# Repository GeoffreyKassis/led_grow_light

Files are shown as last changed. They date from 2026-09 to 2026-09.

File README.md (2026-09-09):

# Grow-light

USB-C PD grow light in two assemblies: an FR-4 controller (`MAIN_BOARD/`) and
a one-layer aluminum LED panel (`LED_BOARD/`), joined by an 8-wire 2×4 IDC
harness. Schematic connectivity and the as-drawn BOM come from KiCad
(`MAIN_BOARD/production/`, `LED_BOARD/production/`). This file records *why*
parts and numbers are what they are.

## Architecture

USB-C is the only power inlet. An **HUSB238** PD sink negotiates the contract
over I2C. An **STM8S003F3** requests **9 V or 12 V** (never 20 V) and PWM-dims
four **TPS61165** boost channels from `PC6`. Each channel drives one isolated
LED string: four 4000 K whites plus one 660 nm red in series.

Boost, not buck: string forward voltage is ~15.8 V, so the converter must sit
above that. TPS61165 VIN is 3–18 V recommended (20 V abs max). A 20 V PDO
leaves no boost headroom and violates that VIN rating.

On/off and dimming are MCU functions. There is no panel switch or pot.

## LED current and power

TPS61165 FB is **200 mV**. String current is set only by the sense resistor:

```
I_LED = V_FB / R_sense
      = 0.200 V / 0.82 Ω
      ≈ 0.244 A
```

A 1 Ω 1206 Basic (`C17928`) is a same-footprint swap: **0.200 A**. Dissipation
in the sense resistor is `I²R` ≈ 49 mW at 0.244 A, so 1206 is thermal margin,
not a requirement.

Nominal string voltage and power (generic 3 V whites / ~3 V red):

```
V_string ≈ 4 × 3.2 V + 3.0 V = 15.8 V
P_string ≈ 15.8 V × 0.244 A  ≈ 3.85 W
P_LEDs   ≈ 4 × 3.85 W        ≈ 15.4 W
```

XP-E2 / Oslon reds are ~2.0–2.1 V, which drops `V_string` a volt or so; the
boost still works. Input current is about **1.7 A at 9 V** or **1.3 A at 12 V**
plus converter and LDO overhead. Product class is still ~20 W at the USB-C
port.

Open-string OVP on TPS61165 is ~38 V. Do not hot-plug the LED harness with
drivers enabled.

## Controller choices

| Role | Part | Why |
|---|---|---|
| PD sink | HUSB238 `C7471904` (DFN-10 3×3) | I2C so firmware picks 9/12 V. CH224K is also Extended and has no I2C. |
| MCU | STM8S003F3P6TR `C52717` | Preferred (no $3 feeder). I2C + TIM1 PWM on remapped `PC6` (set OPT2 AFR0). |
| LED drivers | TPS61165**DRVR** `C122568` ×4 | WSON-6-EP 2×2. Do not pick the SOT-23 `C58756`. VIN 3–18 V, Vout to 38 V. |
| Inductors | CENKER CKCS4030 22 µH `C354592` | 1.0 A Irms / 1.3 A sat. Peak ~0.5 A at 9 V VIN, ~0.83 A at 5 V. No Basic 1 A 4×4. |
| Sense | 820 mΩ 1206 `C2907361` | Sets 0.244 A. True Extended; only same-footprint Basic swap is 1 Ω `C17928`. |
| Freewheel | B5819WS SOD-323 `C7420331` | 40 V / 1 A. Preferred, not a $3 line. |
| Load switch | AO3401A + BZX84C10 + 10 Ω | HUSB238 GATE after contract. 10 V VGS clamp; AO3401A is ±12 V. |
| 3.3 V | HT7533-1 | From switched VIN, 100 mA. Fine at 9/12 V; watch dissipation `(VIN−3.3)×I`. |
| USB-C | 16P `C2927039` | Cheap Extended 7.35 mm. Listing is 3 A / **5 V**; 9–12 V PD is common use but the listing is the weak one. `C165948` is 20 V / 5 A, still Extended. |
| CC ESD | USBLC6-2SC6 `C7519` | CC1/CC2 only. True Extended; no Basic SOT-23-6 equivalent. Do not tie pin 5 to 12 V. |
| Input protect | F1 3 A / 24 V PTC `C7500481`; D9 SMAJ15A | PTC is true Extended. SMAJ15A high-current clamp is ~24.4 V vs TPS61165 20 V abs max — a known gap, not a precise 15 V wall. |

HUSB238 **R2** 49.9 kΩ / **R3** 5.1 kΩ are the typical-app VSET/ISET pair.
5.1 kΩ ISET is about 1.5 A. 49.9 kΩ is **not** a datasheet VSET tap; firmware
must request 9/12 V so the default contract cannot land on 20 V.

TPS61165 VIN ceramics are 25 V. That is correct for 9/12 V and is not a 20 V
design.

## JLCPCB assembly (controller)

Economic PCBA charges **$3 per unique true Extended line**. Preferred parts
often show as “Extended” in the cart and **do not** get that fee.

**No $3 (Preferred):** D1–D4 B5819WS, D8 BZX84C10, D9 SMAJ15A, R2 49.9 kΩ, U2 STM8.

**$3 each (true Extended):** U1 HUSB238, TPS61165DRVR (one fee for four),
L1–L4 (one fee), J2 USB-C, F1 PTC, U3 USBLC6, R4–R7 820 mΩ.

Leave **J1, J3, J4** unselected and solder the TH headers yourself (avoids
the hand-solder surcharge). The only cart swap that drops a $3 line without
touching copper is **R4–R7 → `C17928` 1 Ω**.

## LED panel

Intent is a **1-layer aluminum** MCPCB: SMT on the copper face, no vias, no
through-hole parts (leads can short to the aluminum). The saved KiCad board
is already electrically single-layer (all F.Cu, no B.Cu copper, no vias) but
still declares two copper layers. Set copper layers to **1** before Gerbers
and order aluminum / 1 layer (typically 1.6 mm, 1 oz, white mask).

The checked-in `LED_BOARD/production/grow-light-LEDS.zip` is deliberately
plotted as a **front-copper-only** fabrication package. Do not regenerate it
with KiCad's automatic layer selection while the source board still declares
two copper layers, or an empty `B_Cu` file will be added and the upload may be
treated as a two-layer board.

Do **not** JLC-assemble this panel. Fab bare aluminum; populate by hand
(preheat / hot plate — the core sinks iron heat).

### Heatsink and camera mount

Selected heatsink: **Advanced Thermal Solutions
`ATS-CPX070070025-136-C1-R0`**. It is a 70 × 70 × 25 mm blue-anodized,
coarse-pitch X-cut aluminum heatsink. ATS specifies **2.17 °C/W at 100 LFM**
(~0.5 m/s) airflow; it does not publish a natural-convection value. The LED
panel is expected to put about **10–12 W of heat** into the MCPCB (15.4 W
electrical LED input less emitted light). Thus this heatsink is suitable with
intentional airflow, but is not a qualified passive full-brightness solution.
For a passive revision, target a heatsink rated **≤2.0 °C/W natural
convection** (≤1.5 °C/W preferred for a warm grow enclosure).

The ATS part has a four-corner **63.0 × 63.0 mm** mounting pattern. Direct
MCPCB mounting uses four **3.2 mm NPTH** clearance holes on that grid (centres
3.5 mm from the edges of a 70 mm square), M3 screws, and a thin layer of
thermal grease/TIM against the flat heatsink base. These are mechanical holes,
not component leads: keep front copper clear and insulate the LED-side screw
heads from copper/exposed core with shoulder washers. The current board has no
mounting holes; add them through the KiCad workflow before relying on this
mounting method.

The **1/4-20 UNC camera interface** belongs on a separate metal crossbar or
saddle bolted to the ATS factory holes, not in the heatsink or MCPCB. Capture
a steel 1/4-20 coupling nut in that crossbar for adequate thread engagement;
include an anti-rotation feature and a separate safety tether for overhead use.

This layout: **16× 3030 2-pad** whites (asymmetric A/K) and **4× 3535-3P**
reds (A/K + isolated thermal; pad 3 is unnetted). A 3030 *outline* is not a
3030 *footprint*.

### Whites

Drive ~0.244 A needs a **3 V, ~350–400 mA** 3030. Not mid-power 65 mA parts.

| MPN | Use |
|---|---|
| Cree `JK3030AWT-P-U40EA0000-N0000001` (`C17398997`) | 90 CRI, ~126 lm @ 350 mA. On the LCSC leftover list. |
| Cree `JK3030AWT-P-H40EA0000-N0000001` | Same 3 V / 400 mA max, **80 CRI**, ~154 lm @ 350 mA (~22% more light). Better for plants. |
| Everlight `XI3030P/KKE-5M4014034Z35/2N` | Still manufactured. 4000 K, 80 CRI, 3.05 V, 145 lm @ 350 mA, **max 350 mA**. 3.24×3.00 mm; check pads. |

**Cree JK3030 3 V P class is EOL** (PCN-06128, last-time buy 2026-09-04).
Remaining Digi-Key/Mouser reels are leftover. Cree’s named substitute is
`JB3030SWT-J-H40EA0000-NZ000001` (JB3030S 3 V J class): 65 mA test / 480 mA
max, **757 / Samsung-style pads**, not a 1:1 clone of JK3030 P.

Do not buy 6 V Cree `…EB…` 3030s (Vf ~6.1 V; four of those plus a red blow
the string budget and the 244 mA drive). Do not use Samsung LM301H / EVO
(EOL, and typically max ~200 mA).

### Reds

| MPN | Use |
|---|---|
| Silverlight `M3535N1IRG6U12-660NM` (`C2833507`) | Generic 3535 on LCSC. Weak horticulture part. |
| Cree XP-E2 Photo Red `XPEBPR-L1-0000-00D01` | **Still active.** 660 nm, 3.45 mm, ~2.05 V, 350 mA test / 1 A max. Closest 3535-class upgrade; confirm A/K vs the open thermal pad. |
| ams OSRAM `GH CSSRM6.24-VAA3-1-1-700-R33` | Best 660 nm (~4 µmol/J class). **3.0×3.0 mm ceramic + ~2.2 mm dome, 3-pad (A/K/thermal).** Will not solder to the 2-pad white 3030 or the 3535-3P. |

Samsung LH351H 660 nm is EOL (same lighting-LED shutdown: last ship 2025-12-31).

### Next revision — one footprint

To actually share lands, put the whole panel on **Oslon Square** (ceramic
3-pad 3.0 mm): red `GH CSSRM6.24` + white `GW CSSRM4.HW`. Same stencil,
same pad. Those whites are ~700 mA class and ~$1.50; at 0.244 A they run
cool but you pay 1 W prices. Do not mix Oslon Square pads with
Cree/Everlight 2-pad 3030 whites.

## Firmware notes

- Remap STM8 **OPT2 AFR0** so TIM1_CH1 appears on `PC6`. Default pinout does
  not.
- Hold CTRL low through reset and PD negotiation. Read the contract before
  enabling PWM.
- ~20 kHz PWM is a reasonable starting point; confirm startup does not enter
  TPS61165 EasyScale.
- Four channels at once, on the intended heatsink, after thermal equilibrium.

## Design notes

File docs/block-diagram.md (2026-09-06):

# 20 W USB-C PD Grow Light — System Plan

As-built from the KiCad schematics (main board `grow-light.kicad_sch` +
`led_driver.kicad_sch`, LED panel `grow-light-LEDS.kicad_sch`). Two
assemblies: an FR-4 controller board and a one-layer aluminum LED panel,
joined by an 8-wire LED harness on 2×4 IDC headers. USB-C input is the
power source. An STM8 MCU requests the PD contract over I2C and PWM-dims
four independent TPS61165 boost LED drivers.

## Block diagram

```mermaid
flowchart TB
  PSU["USB-C PD charger"]

  subgraph FR4["FR-4 controller board"]
    J2["J2 USB-C 16P"]
    U3["U3 USBLC6-2SC6<br/>CC1 / CC2 ESD"]
    F1["F1 3 A / 24 V PTC"]
    D7["D7 SMAJ24A TVS"]
    U1["U1 HUSB238<br/>PD sink · I2C"]
    Q1["Q1 AO3401A PMOS<br/>D8 10 V VGS clamp"]
    U7["U7 HT7533 3.3 V LDO"]
    U2["U2 STM8S003F3<br/>I2C to U1 · PWM dim"]
    S1["S1 button"]
    S2["S2 button"]
    Dstat["D5 red / D6 green"]
    J3["J3 PROG"]
    J4["J4 UART"]
    DRV1["U4 TPS61165 · string 1"]
    DRV2["U5 TPS61165 · string 2"]
    DRV3["U11 TPS61165 · string 3"]
    DRV4["U12 TPS61165 · string 4"]
    J1["J1 2×4 IDC"]
  end

  subgraph LED["Aluminum LED panel + heatsink"]
    JP["J1 2×4 IDC SMD"]
    S1s["String 1: 4× 4000 K + 660 nm"]
    S2s["String 2: 4× 4000 K + 660 nm"]
    S3s["String 3: 4× 4000 K + 660 nm"]
    S4s["String 4: 4× 4000 K + 660 nm"]
  end

  PSU -->|"VBUS"| J2
  PSU -->|"CC1 / CC2"| J2
  J2 --> U3 --> U1
  J2 --> F1 --> U1
  F1 --> D7
  F1 --> Q1
  U1 -->|"GATE"| Q1
  Q1 -->|"switched VIN"| DRV1
  Q1 --> DRV2
  Q1 --> DRV3
  Q1 --> DRV4
  Q1 --> U7 --> U2
  U2 -->|"I2C SDA/SCL"| U1
  U2 -->|"PC6 PWM"| DRV1
  U2 --> DRV2
  U2 --> DRV3
  U2 --> DRV4
  S1 --> U2
  S2 --> U2
  U2 --> Dstat
  U2 --- J3
  U2 --- J4
  DRV1 --> J1
  DRV2 --> J1
  DRV3 --> J1
  DRV4 --> J1
  J1 -->|"H1 harness"| JP
  JP --> S1s
  JP --> S2s
  JP --> S3s
  JP --> S4s
```

## Power path

1. USB-C **J2** VBUS through **F1** (3 A hold / 24 V PTC, C7500481) and
   **D7** (SMAJ24A). **U3** protects CC1/CC2 only.
2. **U1** (HUSB238) drives **Q1** (AO3401A) after a PD contract. **D8**
   (BZX84C10) clamps Q1 VGS. **R1** (10 Ω) is the GATE series resistor.
3. Switched VIN feeds four **TPS61165DRV** boost LED drivers and **U7**
   (HT7533, 3.3 V / 100 mA) for the MCU.
4. TPS61165 VIN is 3–18 V. Firmware on **U2** must request a PDO of
   **9 V or 12 V** (not 20 V). A 15.8 V LED string needs boost headroom
   below that voltage.

## Control path

- **U2** STM8S003F3 (TSSOP-20) talks to U1 over I2C (`SDA` / `SCL`) and
  PWM-dims all four driver CTRL pins from `PC6`.
- **S1** (`PD3`) and **S2** (`PD4`) are on-board tactile buttons.
  **D5** (red) and **D6** (green) are 0805 status LEDs.
- **J3** is SWIM/NRST programming. **J4** is UART (`PD5` TX / `PD6` RX).
- There is no panel-mount power switch or dimmer pot. On/off and dimming
  are MCU functions.

## LED drive (per string)

Each hierarchical `led_driver` sheet is one boost channel:

| Item | Schematic |
|---|---|
| Driver | TPS61165DRV, WSON-6-EP, 1.2 MHz, 200 mV FB |
| Inductor | L1–L4 22 µH CENKER CKCS4030, LCSC **C354592**, 4×4×3.0 mm, 1.0 A / 1.3 A sat |
| Freewheel | D1–D4 B5819WS Schottky 40 V / 1 A, SOD-323, **C7420331** |
| Current sense | R4–R7 820 mΩ 1206, **C2907361** → ILED ≈ 200 mV / 0.82 Ω ≈ **0.244 A** |
| VIN cap | C2–C5 4.7 µF 25 V X5R 0805, **C1779** |
| Output cap | C8–C11 1 µF 50 V X5R 0603, **C15849** |
| COMP | C19–C22 220 nF 25 V X7R 0603, **C21120** |

Driver references on the root sheet: **U4, U5, U11, U12**.

## LED panel

Four electrically independent strings. Each string is four 4000 K whites
plus one 660 nm red in series (~15.8 V at 0.244 A ≈ 3.85 W).

| LEDs | Designators | Footprint |
|---|---|---|
| 16 × 4000 K white | D1–D4, D6, D7, D9–D12, D14–D17, D19, D20 | 3030 |
| 4 × 660 nm red | D5, D8, D13, D18 | 3535-3P |
| J1 | 2×4 IDC SMD | to main-board J1 |

The LED schematic does not carry LCSC fields. Previously qualified parts
are Cree `C17398997` (white) and Silverlight `C2833507` (red).

## Power budget (nominal)

| Item | Value |
|---|---|
| PD request | 9 V or 12 V PDO (TPS61165 VIN ≤ 18 V); product still ~20 W class |
| Per string | 4 × 3.2 V white + 3.0 V red ≈ 15.8 V at 0.244 A ≈ 3.85 W |
| Four strings | ≈ 15.4 W LED load |
| Input current | ~1.7 A at 9 V or ~1.3 A at 12 V (plus boost/LDO overhead) |

## Open electrical notes

- Inductor selected: **C354592** CKCS4030 4×4×3.0 mm, 22 µH, 1.0 A Irms /
  1.3 A sat, 225 mΩ. Peak inductor current is ~0.5 A at 9 V VIN, ~0.83 A
  at 5 V. Footprint `Inductor_SMD:L_Cenker_CKCS4030` is already in KiCad
  10. Apply on the `led_driver` sheet (L1–L4 share one symbol) then
  Update PCB from Schematic.
- **R2** 49.9 kΩ and **R3** 5.1 kΩ are the HUSB238 VSET/ISET typical-app
  pair. 5.1 kΩ ISET is about 1.5 A. 49.9 kΩ is not a datasheet VSET tap;
  do not let the default contract land on 20 V.
- TPS61165 VIN capacitors are 25 V parts. Fine at 9/12 V; not a 20 V
  design.

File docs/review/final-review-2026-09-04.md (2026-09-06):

# Grow-light — final-design review, 2026-09-04

## Verdict

The saved boards are routed and DRC-clean under their configured rules. I found no new confirmed signal-wiring fault. The earlier WIP connectivity and placement issues have been addressed. This is a credible prototype candidate, but not yet a fully qualified production design: resolve the assembly/BOM and mechanical questions below before ordering, and validate startup, transient behavior, and temperature on hardware.

No schematic or PCB was changed during this review. Review artifacts were generated in this directory.

## Scope and check results

Reviewed the main schematic, all four instances of its LED-driver subsheet, the LED-panel schematic, exported connectivity, and saved PCB copper/placement views. Both automated design reviews completed without missing-sheet diagnostics.

| Check | Main board | LED board |
|---|---:|---:|
| DRC violations reported | 0 | 0 |
| Unrouted connections reported | 0 | 0 |
| Schematic-parity findings reported | 0 | 0 |
| ERC errors | 5 | 0 |
| ERC warnings | 7 | 0 |
| PCB footprints | 64 | 21 |

Structural connectivity checks found no orphan wires or unintended shorts. Generic manufacturing checks passed, but these do not establish suitability of a particular metal-core fabrication process.

The live KiCad IPC interface failed its document queries. File-based checks and exports succeeded; this review covers saved files, not unsaved editor changes. Exact per-net trace/pad queries through IPC and a complete manufacturer-land-pattern comparison were therefore not completed. DRC cleanliness is not a thermal, EMC, surge, or assembly certification.

## Confirmed improvements

- PC3 and PC4 now connect to the two indicator LEDs.
- R23 provides a 10 kΩ pulldown on the shared PC6/PWM-to-CTRL net.
- HUSB238 ISET now uses R19 (10 kΩ) plus R8 (470 Ω) in series: 10.47 kΩ, approximately 0.29% below the nominal 10.5 kΩ setting. This addresses the earlier resistor discussion without a new resistor value in the BOM.
- D9 is now an SMAJ15A on fused VBUS, with cathode to VBUS and anode to ground.
- The gate pullup, series gate resistor, and gate-source Zener are connected coherently around Q1.
- The four boost channels include their input/output capacitors, 220 nF compensation capacitors, and 0.82 Ω sense resistors.
- MCU VCAP has C16 (1 µF); supply bypassing and reset components are present.
- Main-board and LED-board J1 pin assignments agree: pins 1–8 are 2+, 1+, 2−, 1−, 3−, 4−, 3+, 4+.
- Previously unfinished component placement and routing are no longer reported as outstanding.

The HUSB238 resistor selections should remain tied to the exact ordered device variant. See the [Hynetek datasheet](https://www.hynetek.com/uploadfiles/site/219/news/c16af076-8c40-4e8d-b126-b4f9b83e86ea.pdf).

## Before ordering

### 1. Lock the actual assembly parts and footprints

U1 still has the placeholder-style value `HUSB238_xxxDD`; select the exact orderable suffix and confirm its package and startup behavior. The driver symbol identifies the DRV package, but an explicit orderable MPN should also be recorded for all four instances.

The panel's generic LED values are not enough to specify an assembly. Record manufacturer MPNs and supplier codes, then check anode/cathode numbering, body orientation, and the red LED's third pad against the manufacturer's drawing. This review does not certify the imported EasyEDA footprints.

The previously documented white part, Cree `JK3030AWT-P-U40EA0000-N0000001`, is from the JK3030 3 V family, whose maximum current is 400 mA—not the 240 mA rating of some other 3030 variants. Thus the nominal approximately 244 mA drive is not inherently excessive for that exact white LED. It still requires thermal derating. Confirm that this is what will actually be populated. See the [Cree J Series 3030 datasheet](https://downloads.cree-led.com/files/ds/j/JSeries-3030.pdf).

### 2. Settle panel fabrication, heatsinking, and mounting

The LED board remains configured as a two-copper-layer board, while the project intent calls for a single-layer aluminum panel. Explicitly reconcile the design and fabrication stackup; a generic fabrication check cannot select or validate the metal-core construction for you.

Neither board currently provides dedicated mounting holes. That can be intentional, but decide how the controller is retained and how the LED panel makes reliable thermal contact to its heatsink. Confirm insulation, connector clearance, and strain relief before freezing the outlines. Avoid relying on the cable or USB connector to support the board mechanically.

The controller's USB connector courtyard extends approximately 0.25 mm past the outline. That is not automatically an error for an edge connector; verify the shell position against the enclosure and manufacturer's mechanical drawing. The LED connector's distance from the edge is merely an automated placement heuristic, not a defect for a vertical connector.

### 3. Clean up ERC deliberately

The main-board five errors are power-source declarations on the power network, not newly discovered disconnected signals. Its seven warnings concern unspecified electrical pin types on S1/S2 and U7.

Use appropriate power flags on externally supplied/passive-fed rails and correct the switch/regulator symbol pin types through the library workflow. Do not simply disable these ERC checks globally. Re-run ERC after cleanup.

The automated review also labels five decoupling items as critical. Manual connectivity review does not support adding those parts blindly: C16 supplies VCAP, C1 bypasses U1 VIN, the USB bulk capacitance is downstream of F1, and U3 pin 5 is deliberately unused. In particular, do not connect the USBLC6 clamp-supply pin to negotiated 12 V merely to satisfy that heuristic.

## Firmware and bench validation

### Startup and PWM

PC6 needs the STM8 alternate-function remap to expose TIM1_CH1: set OPT2 AFR0 appropriately; retain the I²C mapping on PB4/PB5. Merely starting a timer will not put its output on default PC6. See the [STM8S003 datasheet](https://www.st.com/resource/pio/datasheet/stm8s003f3.pdf).

Keep CTRL low during reset and power negotiation. Confirm the intended PD supply before enabling substantial LED power; do not assume every source offers 12 V. Test cold start, reset, reconnect, unsupported adapters, and supply loss. No firmware implementation was available to validate.

A roughly 20 kHz PWM is a reasonable starting point. Verify startup timing does not inadvertently enter EasyScale mode. The nominal channel current is 0.2/0.82 ≈ 244 mA; including a 1% resistor and the specified reference tolerance gives approximately 237–251 mA. Four simultaneous channels must be tested. See the [TPS61165 datasheet](https://www.ti.com/lit/ds/symlink/tps61165.pdf).

### Transient protection

Moving D9 after the fuse is an improvement, but an SMAJ15A is not a precise 15 V limiter. Its listed high-current clamp voltage is about 24.4 V, whereas TPS61165 VIN has a 20 V absolute maximum. These specifications describe a protection gap, not a prediction that normal startup will reach 24.4 V. Q1/HUSB238 shutdown helps but does not establish fast-transient protection by itself.

Measure VBUS and switched VIN during hot-plug and negotiation, including the intended cable/source combinations. If guaranteed surge survival is a requirement, qualify a coordinated clamp/disconnect solution; the existing TVS alone is not sufficient evidence. The exact TVS datasheet should be retained with the final BOM.

### Layout and temperature

The boost components are grouped compactly, with short local switching connections and broad ground copper. Preserve that arrangement. Confirm exposed-pad soldering and a short ground return around each driver; thermal vias to the bottom plane are an improvement to consider where practical.

The 40 V boost rectifiers are not automatically wrong: TI's reference designs also use 40 V parts. Their margin against open-string overshoot and switching ringing still needs verification; a higher rating is optional additional margin, not a confirmed required fix. Keep oscilloscope probe ground connections short.

Measure panel temperature, driver/inductor/diode temperature, and U7 temperature at full load and maximum intended ambient after thermal equilibrium. U7 dissipates approximately (12−3.3)×I: 174 mW at 20 mA or 348 mW at 40 mA. Check actual consumption rather than assuming the LDO is cool because it is rated for the input voltage.

## Suggested first-power sequence

1. Inspect polarity, solder bridges, exposed pads, and supply resistance before power.
2. With LEDs disabled, verify negotiated VBUS, switched VIN, 3.3 V, reset, programming, and the CTRL-low default.
3. Start with low brightness; measure each string's current and output voltage.
4. Test all channels at full brightness on the intended heatsink, watching input current and temperature.
5. Check hot-plug/reset recovery and an open-string condition without exceeding instrument ratings. Do not hot-plug the LED harness as a routine operating procedure.

## Evidence

- `final-m.net`, `final-l.net`: exported connectivity used for manual cross-checks.
- `final-m-schematic.png`, `final-l-schematic.png`: schematic exports.
- `final-F.Cu.svg/png`, `final-B.Cu.svg/png`: controller copper views.
- `final-l-copper.svg`: panel copper export.
- `final-main-drc.json`: final all-severity controller DRC result.

This report supersedes the earlier WIP review's outstanding-wiring assessment; it does not replace prototype testing or final assembly-package verification.

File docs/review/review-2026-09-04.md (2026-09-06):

# Grow-light WIP review — 2026-09-04

Reviewed the saved controller schematic hierarchy and PCB, LED schematic and PCB, exported netlists, schematic renders, board renders, placement checks, and project documentation through Konnect. LED pad/trace queries also used the open board through IPC. No design files were changed. Saved-file checks do not certify any unsaved editor changes. This is a design review, not a thermal, EMC, or manufacturing qualification.

## Rule-check results

| Check | Controller | LED panel |
|---|---|---|
| ERC | 5 errors, 9 warnings | 0 errors/warnings |
| DRC | 121 unconnected items, 2 hole-clearance errors, 6 silkscreen warnings | 0 violations/unconnected items |
| Shorted-net / orphan checks | None reported | None reported |
| Automated audit coverage | Complete; 2 schematic files / 5 sheet instances | Complete; 1 sheet |

The controller is unfinished, as expected. Do not interpret its unconnected-item count as 121 independent circuit-design mistakes. Automated audit verdicts were NOT READY for the controller and LOOKS GOOD for the LED board; the latter does not validate LED part selection or heatsinking.

## Functional issue — fix

**D5/D6 cannot be driven.** Their anodes are on `/PC3` and `/PC4`, but those nets contain only the LEDs. U2 pin 13 (PC3) and pin 14 (PC4) are explicitly no-connect. Remove those two no-connect markers and connect matching labels at the MCU. This explains the two isolated-label ERC warnings. Preserve the series resistors R16/R17.

## Power design risks — resolve before committing the layout

**PD current budget and fallback.** Actual wiring is R18 = 10 kΩ on VSET and R15 = 4.7 kΩ on ISET. Hynetek specifies 10 kΩ for 12 V and 4.53 kΩ for 1.5 A; 4.7 kΩ is not its listed nominal tap. Using the documented 15.4 W LED load, converter input alone is approximately 17.1–18.1 W at an assumed 90–85% efficiency, before controller overhead. A 12 V/1.5 A contract therefore has little or no margin; 9 V/1.5 A cannot support full output. Select a documented ISET value and sufficient contract current, then enforce a brightness limit or disable the drivers when the source cannot supply the required power. Firmware should read the negotiated contract before enabling PWM. R14 already provides a 10 kΩ CTRL pulldown.

The 12 V strap is sensible. Do not request 20 V through I2C: it overrides the resistor settings, whereas TPS61165 has an 18 V recommended input ceiling and 20 V absolute maximum. Also ensure the maximum chosen supply remains below the minimum LED-string forward voltage: the boost circuit has a direct input-to-output path even when disabled. U1's exact `HUSB238_xxxDD` suffix remains unspecified; variants differ in fallback behavior. Source: [Hynetek datasheet, tables 5/6 and I2C operation](https://www.hynetek.com/uploadfiles/site/219/news/aabbbbdb-48c9-4a44-a6dc-2c15f53282e6.pdf).

**D7/F1 protection coordination.** D7 SMAJ24A is on USB_VBUS, before F1. F1 therefore cannot interrupt current into a failed-short D7. Decide whether the intended protection is upstream current limiting or a fuse ahead of the TVS branch. A 24 V TVS does not clamp at 24 V; representative SMAJ24A specifications give 26.7–29.5 V breakdown and 38.9 V rated clamping. It does not establish a safe transient ceiling for the downstream circuitry. Select protection by actual clamping voltage/current and component absolute maxima; a lower nominal TVS alone is not proof of adequate protection. Verify the exact fitted manufacturer's data. Reference: [Littelfuse SMAJ series](https://www.littelfuse.com/~/media/electronics/datasheets/tvs_diodes/littelfuse_tvs_diode_smaj_datasheet.pdf.pdf).

**Open LED / unplugged harness conditions.** TPS61165's SW overvoltage threshold is 37–39 V. Check D1–D4's 40 V Schottky margin including ringing and hot operation; consider a higher-voltage part if losses are acceptable. C8–C11 are 50 V parts, but effective capacitance at elevated DC bias also matters. Treat powered harness reconnection as a validation case, including current transients and FB stress; prefer connecting the panel while unpowered. Source: [TI TPS61165 datasheet](https://www.ti.com/lit/ds/symlink/tps61165.pdf).

**U7 thermal budget.** It is connected to pre-switch VBUS, which allows MCU startup before the LED load is enabled. At 12 V, a 20 mA 3.3 V load dissipates approximately 174 mW in the LDO; 40 mA dissipates 348 mW. Check actual MCU/peripheral consumption and the exact HT7533 thermal limits with the available copper. Label J3/J4 clearly: their power pins connect directly to the board's 3.3 V rail, so externally supplied programmer/UART power needs an intentional connection policy.

## Controller layout

- J2 has two internal footprint hole-clearance violations: 0.2036 mm actual versus the configured 0.25 mm requirement. Check the connector drawing and manufacturer capability before modifying the footprint or applying a narrow exception. Do not relax all clearances to hide it.
- D5/D6, R9–R14, and R16/R17 remain outside the 55 × 50 mm outline. These are placement backlog. The additional J2 courtyard overhang is only 0.25 mm at the connector mouth and may be intentional.
- The four repeated boost clusters are compact, and the separation from the MCU is useful. Finish their high-current ground paths and exposed-pad connections before signal routing. DRC currently flags ground disconnections including driver exposed pads. Keep the SW–diode–output-capacitor loop short, connect input bypass returns locally, and keep FB/COMP away from SW copper. Provide a ground plane and thermal connections consistent with TI's layout guidance.
- Only Default netclass exists: 0.2 mm routing width and 0.2 mm clearance. Establish power routing sizes for the common input and ground paths based on aggregate current, copper thickness, and temperature rise. The minimum-width rule is not a current-rating check.
- Clean up six silkscreen warnings around D4, F1/D7, C10, C11, and U2/C18 after placement settles. Add useful connector pin labels and accessible GND, 3.3 V, switched VIN, PWM, and sense-node test access.
- Decide enclosure retention and connector insertion support before completing routing; neither board render shows mounting holes.

## LED panel

The netlist contains four independent five-LED series strings, with consistent electrical polarity. J1 assignments match the controller exactly: pins 1–8 = 2+, 1+, 2−, 1−, 3−, 4−, 3+, 4+. The panel has 44 routed segments, all F.Cu and 1 mm wide.

**Thermal design remains to be established.** The panel's 1 mm interconnects are not a heatsink specification. Define the aluminum-core dielectric and thermal conductivity, LED thermal land requirements, interface material, mounting pressure, and heatsink. Provide temperature measurement or thermal cutoff/derating if unattended operation warrants it; controller-IC thermal shutdown cannot measure panel temperature.

D5's third footprint pad has no electrical net, and the red LEDs use a generic two-pin symbol with a three-pad footprint. That can be correct for an isolated thermal pad, but verify the exact red LED drawing, pad polarity and center-pad connection requirements. The LED schematic does not identify exact MPNs or datasheets, so footprint-to-part compatibility and junction-temperature limits remain unverified. Do not blindly ground that center pad.

The project metadata still declares two copper layers despite the documented single-layer aluminum intent. All queried tracks are on top, so this is not evidence of unwanted bottom routing. Make the fabrication stackup and outputs explicit. Retain J1's position if it suits cable access; the placement tool's arbitrary edge-distance deduction is not a defect for this vertical connector. Add cable strain relief and panel retention.

## ERC and documentation cleanup

The five ERC errors concern undriven power pins. Correct U7's unspecified electrical pin types and add justified power flags at externally/passively fed supplies. The switch pin-type warnings similarly reflect library metadata. Do not blanket-disable ERC.

Automated missing-capacitor reports for U2 VCAP and U1 VIN are false positives: C16 = 1 µF and C1 = 1 µF are connected. Do not replace C16 with the audit's generic 100 nF suggestion: ST specifies 470–3300 nF for VCAP. [STM8S003 datasheet](https://www.st.com/resource/pio/datasheet/stm8s003f3.pdf).

U3 pin 5 is deliberately unconnected; that is not a missing supply bypass to fix automatically. In particular, do not tie USBLC6-2's VBUS pin to the 12 V PD rail; its internal protection is intended for a low-voltage bus. Validate the chosen CC protection arrangement for the desired ESD and short-to-VBUS behavior. [ST USBLC6-2 datasheet](https://www.st.com/resource/en/datasheet/usblc6-2.pdf).

The existing BOM/block diagram need reconciliation: R1 is the VIN filter resistor, R2/R3 are the gate network, R18/R15 set voltage/current, U7 is upstream of Q1, and D7 is upstream of F1. The BOM still lists absent R8 and omits present R18. The current 0.82 Ω sense resistors give about 244 mA; the documented nominal LED load is 15.4 W rather than 20 W of LED output.

Suggested order: restore status-LED connections; settle contract current, protection and exact parts; settle heatsink/mechanics; complete power/ground routing and remaining placement; then rerun ERC/DRC and validate startup, dimming, fallback and temperatures on hardware.

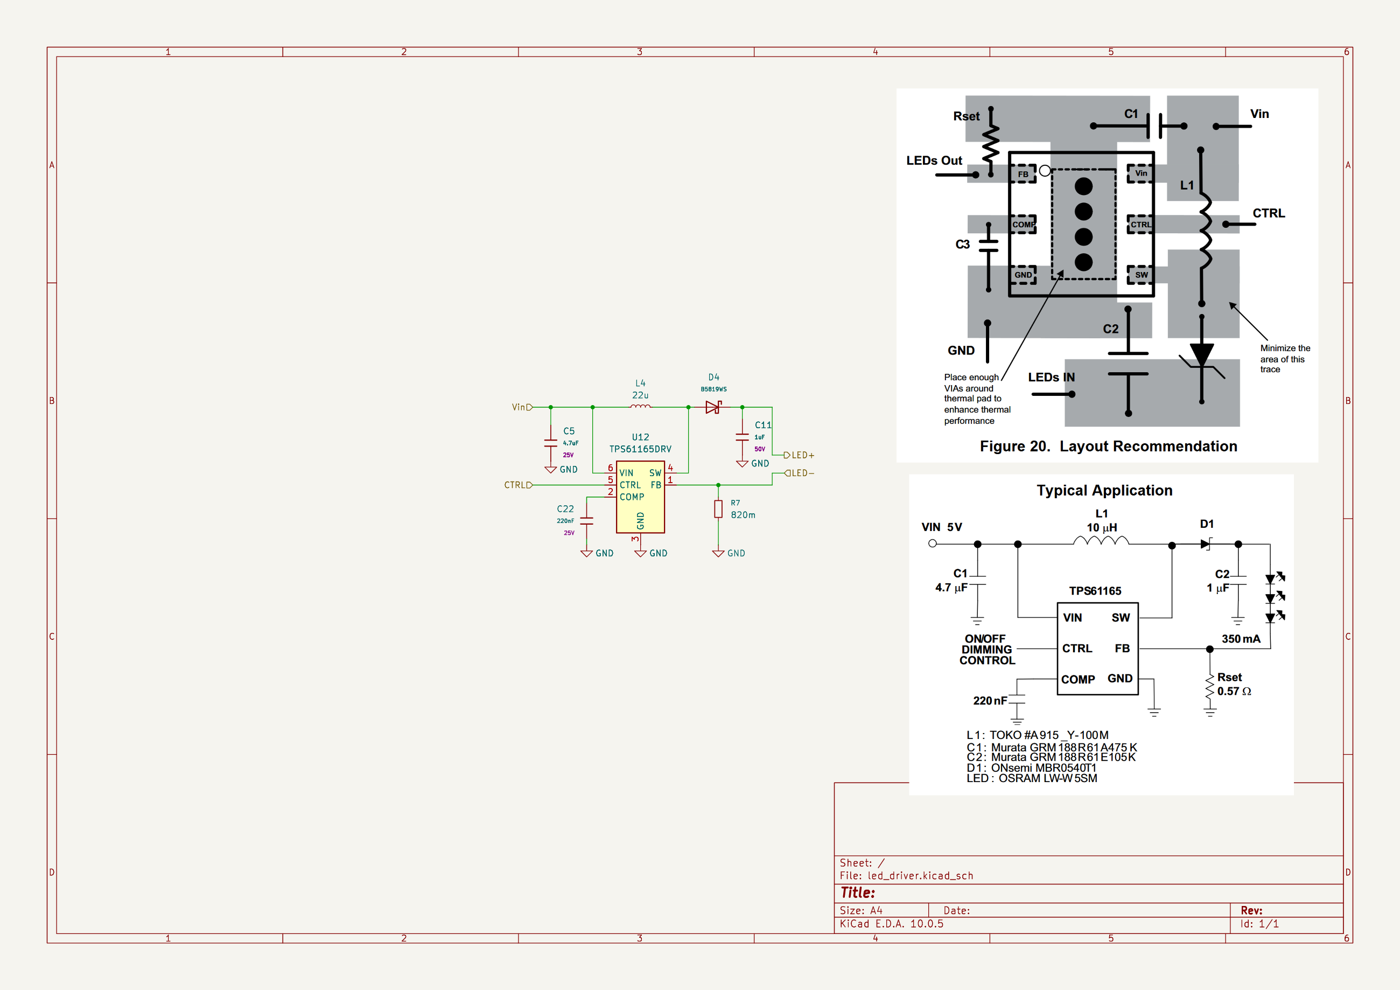
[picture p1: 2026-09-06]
docs/review/schematic1.png

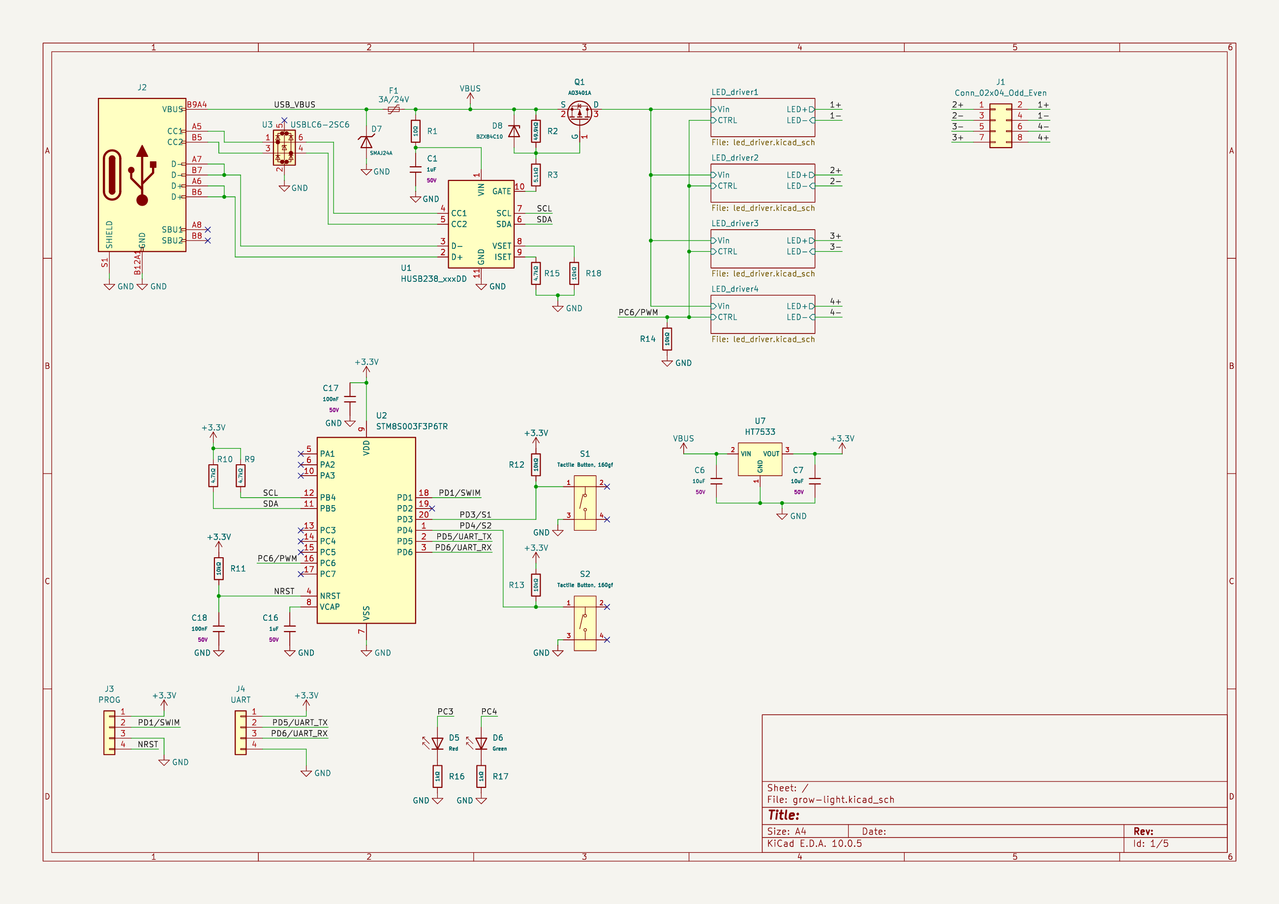
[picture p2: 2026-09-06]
docs/review/schematic0.png

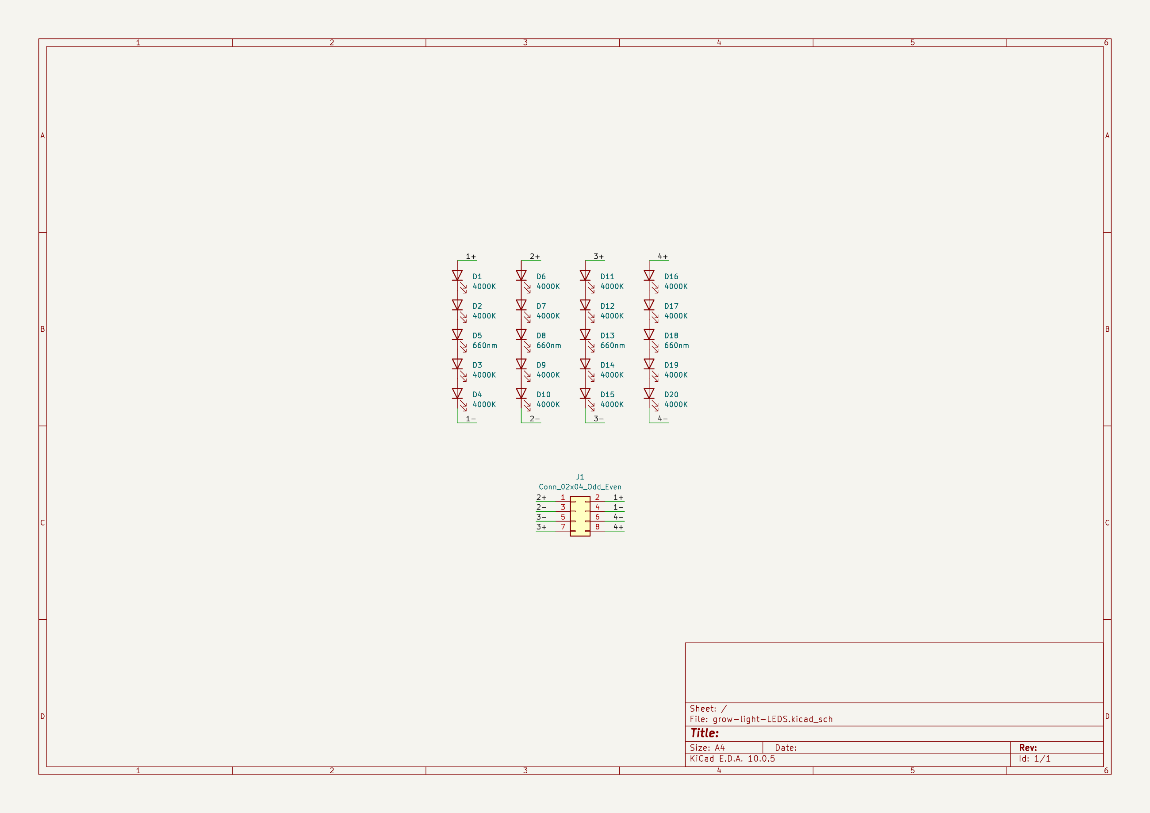
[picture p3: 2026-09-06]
docs/review/final-l-schematic.png

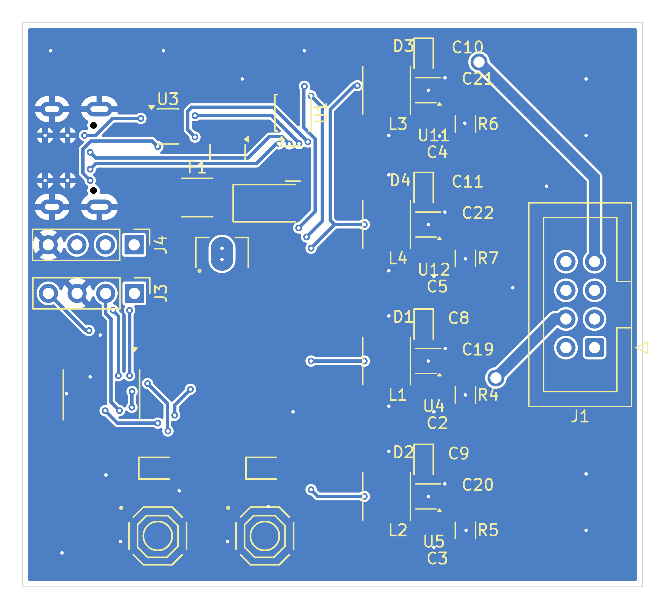
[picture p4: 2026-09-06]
docs/review/final-B.Cu.png

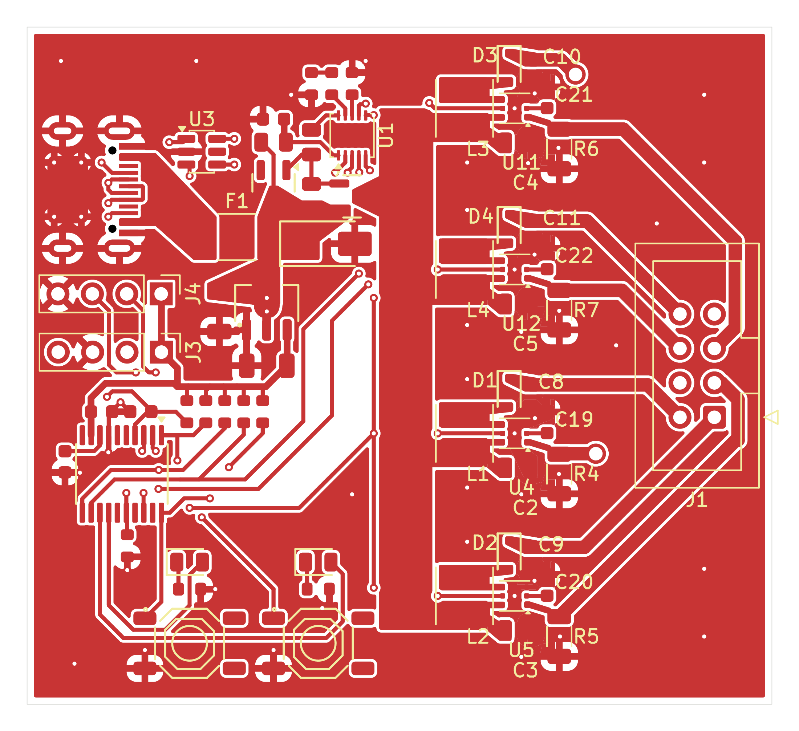
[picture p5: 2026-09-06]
docs/review/final-F.Cu.png

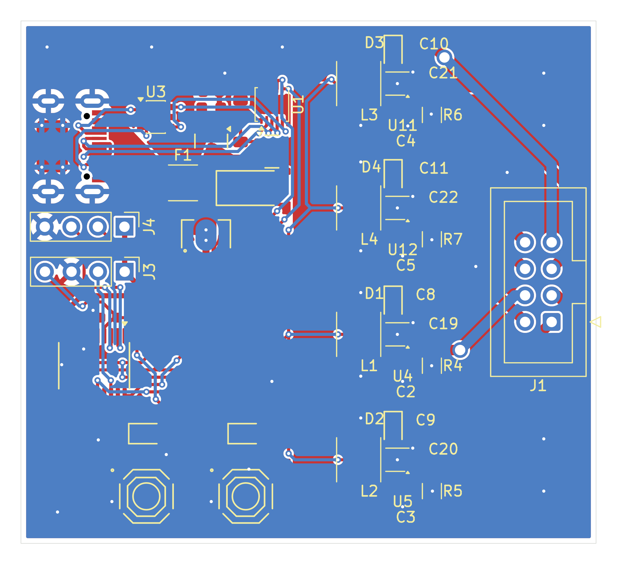
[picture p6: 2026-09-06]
docs/review/final-m-copper.png

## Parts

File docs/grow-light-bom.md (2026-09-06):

# 20 W USB-C PD Grow Light — Schematic BOM

This BOM is taken from the KiCad schematics as of 2026-09-04, not from the
older pre-schematic parts list. Re-check LCSC stock and JLCPCB assembly
eligibility at checkout.

## Frozen electrical architecture (as drawn)

USB-C PD sink (**U1** HUSB238) plus **STM8S003F3** (**U2**) on a 3.3 V
**HT7533** rail. The MCU requests the PDO over I2C and PWM-dims four
**TPS61165DRV** boost channels. There is no panel-mount switch or pot.

The LED board has four electrically independent, constant-current strings:

```
String 1..4:  4000K - 4000K - 4000K - 4000K - 660nm
                 0.244 A nominal (200 mV / 0.82 Ω)
```

At nominal forward voltages of 3.2 V (white) and 3.0 V (red), each string
is about 15.8 V / 3.85 W. LED load is about 15.4 W.

TPS61165 is a **boost** converter with 3–18 V VIN. Firmware must request
**9 V or 12 V**, not 20 V.

## Controller board (from `grow-light.kicad_sch` + `led_driver.kicad_sch`)

| Refs | Qty | Value / MPN | LCSC | Footprint |
|---|---|---|---|---|
| J2 | 1 | USB-C 16P | C2927039 | TYPE-C 16-pin SMD |
| U1 | 1 | HUSB238 | C7471904 (not on symbol) | WDFN-10 3×3 |
| U3 | 1 | USBLC6-2SC6 | C7519 | SOT-23-6 |
| F1 | 1 | 3 A / 24 V PTC | C7500481 | 1812 |
| D7 | 1 | SMAJ24A | C19077541 | SMA |
| Q1 | 1 | AO3401A | C15127 | SOT-23 |
| D8 | 1 | BZX84C10 | C19077470 | SOT-23 |
| R1 | 1 | 10 Ω | C17415 | 0805 |
| R2 | 1 | 49.9 kΩ | C17719 | 0805 |
| R3 | 1 | 5.1 kΩ | C27834 | 0805 |
| C1, C16 | 2 | 1 µF 50 V X5R | C15849 | 0603 |
| C6, C7 | 2 | 10 µF 50 V X5R | C13585 | 1206 |
| C17, C18 | 2 | 100 nF 50 V X7R | C14663 | 0603 |
| U7 | 1 | HT7533-1 3.3 V LDO | C14289 | SOT-89-3 |
| U2 | 1 | STM8S003F3P6TR | C52717 | TSSOP-20 |
| S1, S2 | 2 | TS-1187A-B-A-B | C318884 | 5.1 mm tactile |
| D5 | 1 | Red 0805 | C84256 | 0805 |
| D6 | 1 | Green 0805 | C2297 | 0805 |
| R16, R17 | 2 | 1 kΩ | C21190 | 0603 |
| R8, R11–R14 | 5 | 10 kΩ | C17414 | 0805 |
| R9, R10, R15 | 3 | 4.7 kΩ | C23162 | 0603 |
| J3 | 1 | PROG 1×4 | — | TH 2.54 mm |
| J4 | 1 | UART 1×4 | — | TH 2.54 mm |
| J1 | 1 | 2×4 IDC TH | — | IDC 2.54 mm |
| U4, U5, U11, U12 | 4 | TPS61165DRV | — | WSON-6-EP 2×2 |
| L1–L4 | 4 | 22 µH CKCS4030 | **C354592** | 4×4×3.0 mm |
| D1–D4 | 4 | B5819WS | C7420331 | SOD-323 |
| R4–R7 | 4 | 820 mΩ | C2907361 | 1206 |
| C2–C5 | 4 | 4.7 µF 25 V X5R | C1779 | 0805 |
| C8–C11 | 4 | 1 µF 50 V X5R | C15849 | 0603 |
| C19–C22 | 4 | 220 nF 25 V X7R | C21120 | 0603 |

## LED panel (from `grow-light-LEDS.kicad_sch`)

| Refs | Qty | Value | LCSC | Footprint |
|---|---|---|---|---|
| D1–D4, D6, D7, D9–D12, D14–D17, D19, D20 | 16 | 4000 K white | C17398997 (not on sheet) | 3030 |
| D5, D8, D13, D18 | 4 | 660 nm red | C2833507 (not on sheet) | 3535-3P |
| J1 | 1 | 2×4 IDC SMD | — | IDC 2.54 mm SMD |

## What changed vs the pre-schematic BOM

| Old plan | Now in schematic |
|---|---|
| AL8860Q buck, 20 V PD | TPS61165 boost, MCU-selected 9/12 V PD |
| No MCU / no 3.3 V | STM8S003F3 + HT7533 |
| RV1 pot + SW1 | S1/S2 buttons + PWM on PC6 |
| L1–L4 68 µH C5291881 | L1–L4 **22 µH C354592** CKCS4030 4×4 mm (was C354634 6×6) |
| 0.402 Ω sense → 0.249 A | 820 mΩ sense → 0.244 A |
| SK24 SMA Schottky | B5819WS SOD-323 |
| USB-C C165948 | USB-C C2927039 |
| Fuse 1.5 A | Fuse 3 A / 24 V C7500481 |
| 12 V VGS zener | 10 V BZX84C10 |
| Off-board switch/pot harness | On-board UI only |

## Ordering notes

1. Import `grow-light-bom.csv` and re-check live stock.
2. TPS61165DRV has no LCSC on the symbol — pick a JLC-stocked WSON-6
   (`TPS61165DRV`) before assembly.
3. Do not substitute a 20 V PD request: it exceeds TPS61165 VIN.
4. LED LCSC numbers are still the previously qualified Cree / Silverlight
   parts; they are not written on the LED schematic.

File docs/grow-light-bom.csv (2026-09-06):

Assembly | Designators | Qty | Description | Manufacturer | MPN | LCSC_JLC_Part | Class | Footprint | Notes
LED panel | D1-D4 D6 D7 D9-D12 D14-D17 D19 D20 | 16 | 4000 K white LED | Cree LED | JK3030AWT-P-U40EA0000-N0000001 | C17398997 | LCSC | 3030 | Schematic value 4000K; LCSC not on LED sheet. Previously qualified. Drive at ~0.244 A.
LED panel | D5 D8 D13 D18 | 4 | 660 nm deep-red LED | Silverlight | M3535N1IRG6U12-660NM | C2833507 | LCSC | 3535-3P | Schematic value 660nm; LCSC not on LED sheet. Previously qualified. Drive at ~0.244 A.
LED panel | J1 | 1 | 2x4 IDC header SMD vertical | Generic | IDC-2x4-P2.54-SMD |  | Manual | IDC-Header_2x04_P2.54mm_Vertical_SMD | Mates with main-board J1.
Controller | J2 | 1 | USB-C receptacle 16-pin | Generic | USB-TYPE-C-16P | C2927039 | Extended | TYPE-C-SMD_HX-TYPE-C-16PIN | Power + CC only.
Controller | U1 | 1 | USB-PD 3.0 sink controller | Hynetek | HUSB238_xxxDD | C7471904 | Extended | WDFN-10-1EP 3x3mm | I2C to U2. MCU must request 9 V or 12 V PDO. LCSC not on symbol; C7471904 is the prior HUSB238_002DD.
Controller | U3 | 1 | 2-channel ESD protector | STMicroelectronics | USBLC6-2SC6 | C7519 | Basic | SOT-23-6 | Protect CC1 and CC2 only; place at J2.
Controller | F1 | 1 | 3 A / 24 V PTC resettable fuse | Generic | 3A/24V-1812 | C7500481 | Extended | 1812 | Immediately after USB-C VBUS.
Controller | D7 | 1 | 24 V unidirectional TVS | hongjiacheng | SMAJ24A | C19077541 | Preferred | SMA | VBUS surge clamp.
Controller | Q1 | 1 | 30 V P-channel MOSFET | Alpha & Omega Semiconductor | AO3401A | C15127 | Basic | SOT-23 | PD-controlled load switch.
Controller | D8 | 1 | 10 V gate-source zener | hongjiacheng | BZX84C10 | C19077470 | Preferred | SOT-23 | Clamp Q1 VGS.
Controller | R1 | 1 | 10 ohm 1% GATE series | UNI-ROYAL | 0805W8F100JT5E | C17415 | Basic | 0805 | HUSB238 GATE series resistor.
Controller | R2 | 1 | 49.9 kohm 1% | UNI-ROYAL | 0805W8F4992T5E | C17719 | Preferred | 0805 | HUSB238 VSET typical-app resistor; not a datasheet tap. Firmware sets PDO.
Controller | R3 | 1 | 5.1 kohm 1% | UNI-ROYAL | 0805W8F5101T5E | C27834 | Basic | 0805 | HUSB238 ISET typical-app resistor (~1.5 A).
Controller | C1 C16 | 2 | 1 uF 50 V X5R | Samsung Electro-Mechanics | CL10A105KB8NNNC | C15849 | Basic | 0603 | HUSB238 / local 50 V ceramics.
Controller | C6 C7 | 2 | 10 uF 50 V X5R | Samsung Electro-Mechanics | CL31A106KBHNNNE | C13585 | Basic | 1206 | Bulk input ceramics.
Controller | C17 C18 | 2 | 100 nF 50 V X7R | YAGEO | CC0603KRX7R9BB104 | C14663 | Basic | 0603 | Decoupling.
Controller | U7 | 1 | 3.3 V 100 mA LDO | Holtek | HT7533-1 | C14289 | Basic | SOT-89-3 | MCU rail from switched VIN. VIN abs max 30 V.
Controller | U2 | 1 | STM8 8-bit MCU 8 KB Flash | STMicroelectronics | STM8S003F3P6TR | C52717 | Preferred | TSSOP-20 | I2C to U1; PWM on PC6 to driver CTRL; S1/S2; UART; SWIM.
Controller | S1 S2 | 2 | Tactile button 160 gf SPST | XKB Connectivity | TS-1187A-B-A-B | C318884 | Basic | 5.1 mm SMD | S1=PD3 S2=PD4.
Controller | D5 | 1 | Red 0805 indicator LED | Foshan NationStar | NCD0805R1 | C84256 | Basic | 0805 | Status.
Controller | D6 | 1 | Green 0805 indicator LED | Hubei KENTO | KT-0805G | C2297 | Basic | 0805 | Status.
Controller | R16 R17 | 2 | 1 kohm 1% | UNI-ROYAL | 0603WAF1001T5E | C21190 | Basic | 0603 | D5/D6 current limit.
Controller | R8 R11-R14 | 5 | 10 kohm 1% | UNI-ROYAL | 0805W8F1002T5E | C17414 | Basic | 0805 | Pull-ups (I2C/buttons/CTRL as wired).
Controller | R9 R10 R15 | 3 | 4.7 kohm 1% | UNI-ROYAL | 0603WAF4701T5E | C23162 | Basic | 0603 | Pull-ups.
Controller | J3 | 1 | 1x4 programming header | Generic | PinHeader_1x04_P2.54 |  | Manual | TH 2.54 mm | SWIM / NRST.
Controller | J4 | 1 | 1x4 UART header | Generic | PinHeader_1x04_P2.54 |  | Manual | TH 2.54 mm | PD5 TX / PD6 RX.
Controller | J1 | 1 | 2x4 IDC header vertical TH | Generic | IDC-2x4-P2.54-TH |  | Manual | IDC-Header_2x04_P2.54mm_Vertical | LED harness to panel J1.
Controller | U4 U5 U11 U12 | 4 | Boost LED driver 3-18 VIN 38 Vout | Texas Instruments | TPS61165DRV |  | Extended | WSON-6-1EP 2x2mm | One per string. 200 mV FB 1.2 MHz. No LCSC on symbol. VIN must stay <= 18 V.
Controller | L1-L4 | 4 | 22 uH shielded power inductor 1.0 A / 1.3 A sat | CENKER | CKCS4030-22uH/M | C354592 | Extended | 4x4x3.0 mm | Same CKCS family as the old 6x6 C354634. KiCad footprint Inductor_SMD:L_Cenker_CKCS4030. LCSC stock ~1560.
Controller | D1-D4 | 4 | 40 V 1 A Schottky | hongjiacheng | B5819WS | C7420331 | Preferred | SOD-323 | Freewheel per boost channel.
Controller | R4-R7 | 4 | 820 mOhm current-sense | Generic | 0R82-1206 | C2907361 | Extended | 1206 | Sets ~0.244 A at 200 mV FB.
Controller | C2-C5 | 4 | 4.7 uF 25 V X5R | Samsung Electro-Mechanics | CL21A475KAQNNNE | C1779 | Basic | 0805 | TPS61165 VIN ceramic per channel.
Controller | C8-C11 | 4 | 1 uF 50 V X5R | Samsung Electro-Mechanics | CL10A105KB8NNNC | C15849 | Basic | 0603 | TPS61165 output ceramic per channel.
Controller | C19-C22 | 4 | 220 nF 25 V X7R | Samsung Electro-Mechanics | CL10B224KA8NNNC | C21120 | Basic | 0603 | TPS61165 COMP per channel.
Off-board | H1 | 1 | 8-conductor harness | Generic | 8x24AWG-harness |  | Manual | Wire | Four isolated LED-string pairs on 2x4 IDC.
Off-board | H2 | 1 | Aluminum heatsink and TIM | Generic | Passive-heatsink |  | Mechanical | Mechanical | Size by thermal test.

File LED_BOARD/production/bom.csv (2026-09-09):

Designator | Footprint | Quantity | Value | LCSC Part #
D1, D10, D11, D12, D14, D15, D16, D17, D19, D2, D20, D3, D4, D6, D7, D9 | LED-SMD_L3.0-W3.0-RD-1 | 16 | 4000K | C17398997
D13, D18, D5, D8 | LED-SMD_3P-L3.5-W3.5-RD-C | 4 | 660nm | C2833507
J1, J2 | FLIPPED_PRPC004SBCN-M71RC | 2 | Conn_01x04 | PRPC004SBCN-M71RC

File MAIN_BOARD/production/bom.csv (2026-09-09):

Designator | Footprint | Quantity | Value | LCSC Part #
C1, C10, C11, C16, C8, C9 | C_0603 | 6 | 1uF | C15849
C17, C18 | C_0603 | 2 | 100nF | C14663
C19, C20, C21, C22 | C_0603 | 4 | 220nF | C21120
C2, C3, C4, C5 | C_0805 | 4 | 4.7uF | C1779
C6, C7 | C_1206 | 2 | 10uF | C13585
D10, D11, D12, D7 | D_SOD-323 | 4 | B16WS | C7420327
D5 | D_0805 | 1 | Red | C84256
D6 | D_0805 | 1 | Green | C2297
D8 | D_SOT-23 | 1 | BZX84C10 | C19077470
D9 | D_SMA | 1 | SMAJ15A | C19077535
F1 | 1812 | 1 | 3A/24V | C7500481
J1 | PinHeader_2x04_P2.54mm_Vertical | 1 | Conn_02x04_Odd_Even
J2 | TYPE-C-SMD_HX-TYPE-C-16PIN | 1 | Connector, USB-TYPE-C-16P | C2927039
J3 | PinHeader_1x04_P2.54mm_Vertical | 1 | PROG
J4 | PinHeader_1x04_P2.54mm_Vertical | 1 | UART
L1, L2, L3, L4 | L_Cenker_CKCS4030 | 4 | 22u | C354592
Q1 | Q_SOT-23 | 1 | AO3401A | C15127
R1 | R_0805 | 1 | 10Ω | C17415
R10, R9 | R_0603 | 2 | 4.7kΩ | C23162
R11 | R_0603 | 1 | 49.9kΩ | C23184
R16, R17 | R_0603 | 2 | 1kΩ | C21190
R18, R19, R20, R21, R22, R23 | R_0603 | 6 | 10kΩ | C25804
R3 | R_0805 | 1 | 5.1kΩ | C27834
R4, R5, R6, R7 | 1206 | 4 | 820m | C2907361
R8 | R_0603 | 1 | 470Ω | C23179
S1, S2 | SW-SMD_4P-L5.1-W5.1-P3.70-LS6.5-TL-2 | 2 | Tactile Button, 160gf | C318884
TP_3V3, TP_GND1, TP_PWM1, TP_VBUS1, TP_VIN1 | PinHeader_1x01_P1.00mm_Vertical | 5 | TestPoint
U1 | WDFN-10-1EP_3x3mm_P0.5mm_EP1.8x2.5mm | 1 | HUSB238_xxxDD | C7471904
U11, U12, U4, U5 | WSON-6-1EP_2x2mm_P0.65mm_EP1x1.6mm | 4 | TPS61165DRV | C122568
U2 | TSSOP-20_4.4x6.5mm_P0.65mm | 1 | STM8S003F3P6TR | C52717
U3 | SOT-23-6 | 1 | USBLC6-2SC6 | C7519
U7 | SOT-89-3_L4.5-W2.5-P1.50-LS4.2-BR | 1 | HT7533 | C14289

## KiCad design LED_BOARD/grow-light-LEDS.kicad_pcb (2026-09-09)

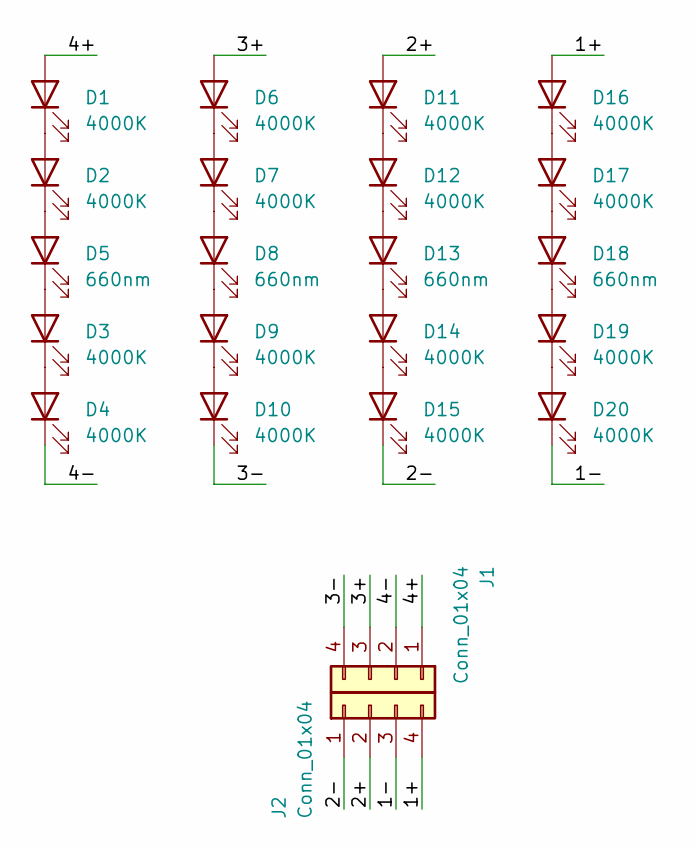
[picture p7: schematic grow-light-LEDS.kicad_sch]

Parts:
D1, D2, D3, D4, D6, D7, D9, D10, D11, D12, D14, D15, D16, D17, D19, D20: 4000K; LED-SMD_L3.0-W3.0-RD-1; LCSC C17398997
D5, D8, D13, D18: 660nm; LED-SMD_3P-L3.5-W3.5-RD-C; LCSC C2833507
J1, J2: Conn_01x04; FLIPPED_PRPC004SBCN-M71RC; MPN PRPC004SBCN-M71RC

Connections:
/1+: D16.2 (A), J2.4
/1-: D20.1 (K), J2.3
/2+: D11.2 (A), J2.2
/2-: D15.1 (K), J2.1
/3+: D6.2 (A), J1.3
/3-: D10.1 (K), J1.4
/4+: D1.2 (A), J1.1
/4-: D4.1 (K), J1.2
unnamed: D1.1 (K), D2.2 (A)
unnamed: D2.1 (K), D5.2 (A)
unnamed: D3.2 (A), D5.1 (K)
unnamed: D3.1 (K), D4.2 (A)
unnamed: D6.1 (K), D7.2 (A)
unnamed: D7.1 (K), D8.2 (A)
unnamed: D8.1 (K), D9.2 (A)
unnamed: D9.1 (K), D10.2 (A)
unnamed: D11.1 (K), D12.2 (A)
unnamed: D12.1 (K), D13.2 (A)
unnamed: D13.1 (K), D14.2 (A)
unnamed: D14.1 (K), D15.2 (A)
unnamed: D16.1 (K), D17.2 (A)
unnamed: D17.1 (K), D18.2 (A)
unnamed: D18.1 (K), D19.2 (A)
unnamed: D19.1 (K), D20.2 (A)

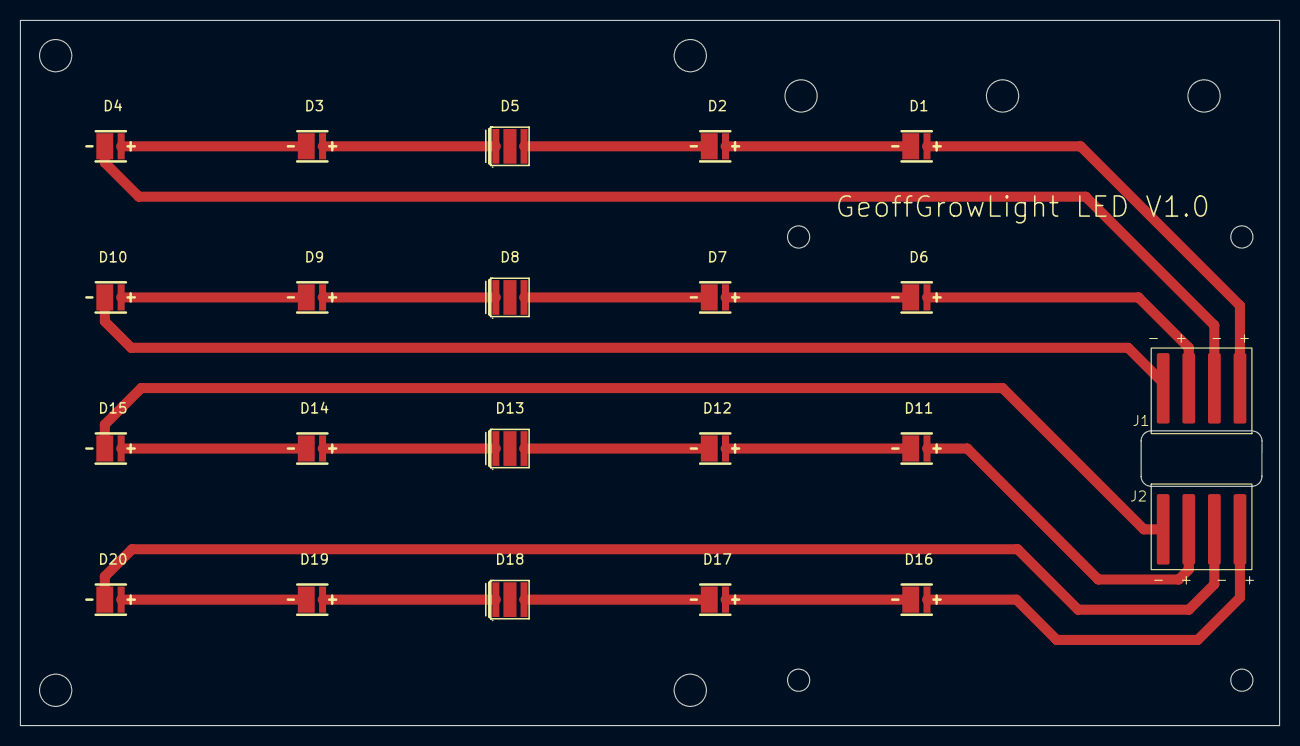
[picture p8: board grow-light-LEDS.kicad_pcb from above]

Board: 2 copper layers, 125.0 x 70.0 mm, 22 parts (0 on the bottom side), 24 nets.

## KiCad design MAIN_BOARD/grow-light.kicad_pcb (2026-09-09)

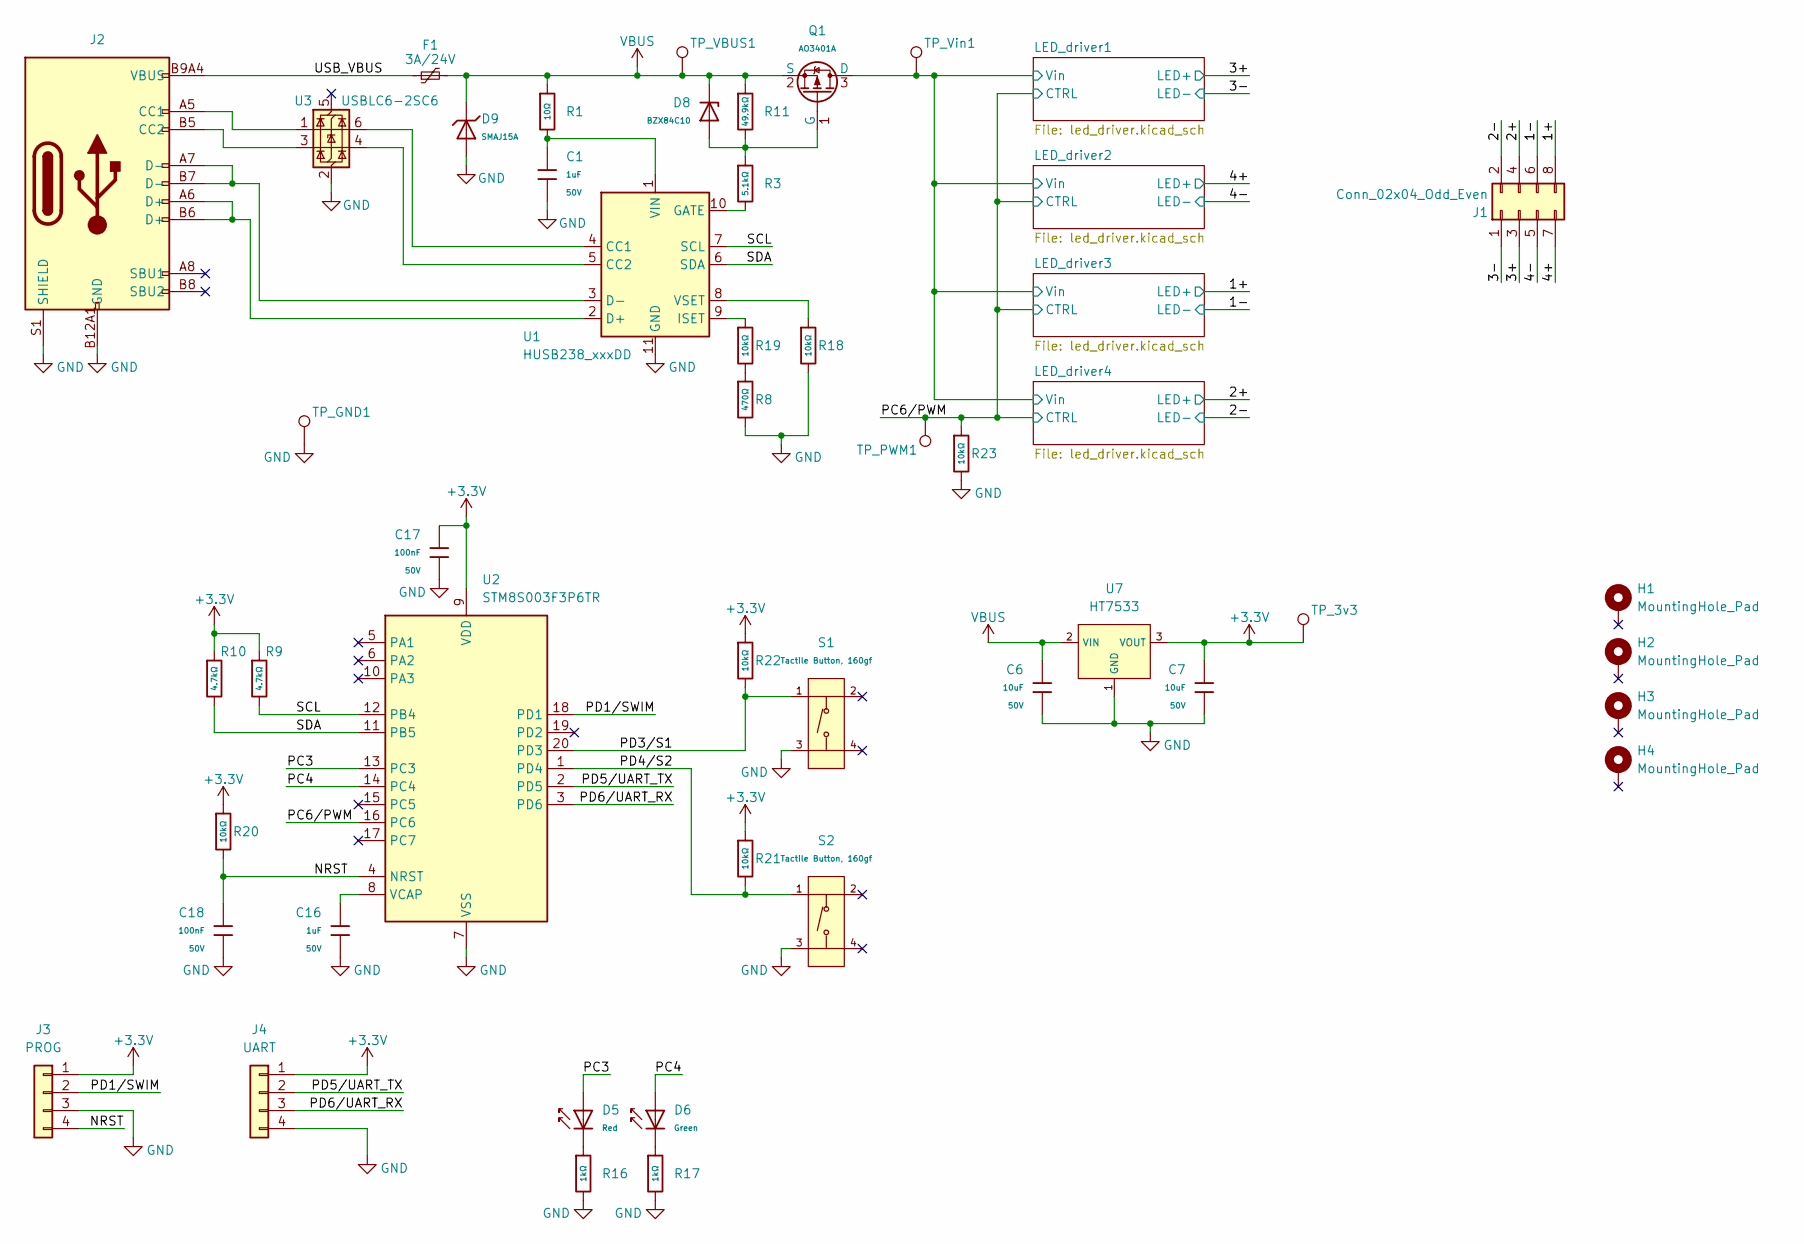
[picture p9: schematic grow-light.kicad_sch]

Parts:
C1, C16: 1uF; C_0603; Voltage Rated 50V; Tolerance ±10%; Part CL10A105KB8NNNC; LCSC C15849
C6, C7: 10uF; C_1206; Voltage Rated 50V; Tolerance ±10%; Part CL31A106KBHNNNE; LCSC C13585
C17, C18: 100nF; C_0603; Voltage Rated 50V; Tolerance ±10%; Part CC0603KRX7R9BB104; LCSC C14663
D5: Red; D_0805; Forward Voltage (VF) 1.6V~2.6V; Part NCD0805R1; LCSC C84256
D6: Green; D_0805; Part KT-0805G; LCSC C2297
D8: BZX84C10; D_SOT-23; Part BZX84C10; LCSC C19077470
D9: SMAJ15A; D_SMA; Part SMAJ15A; LCSC C19077535
F1: 3A/24V; Fuse_1812_4532Metric; LCSC C7500481
H1, H2, H3, H4: MountingHole_Pad; MountingHole_2.2mm_M2_Pad_Via
J1: Conn_02x04_Odd_Even; PinHeader_2x04_P2.54mm_Vertical
J2: Connector, USB-TYPE-C-16P; TYPE-C-SMD_HX-TYPE-C-16PIN; LCSC C2927039
J3: PROG; PinHeader_1x04_P2.54mm_Vertical
J4: UART; PinHeader_1x04_P2.54mm_Vertical
Q1: AO3401A; Q_SOT-23; Part AO3401A; LCSC C15127
R1: 10Ω; R_0805; Overload Voltage (Max) 150V; Tolerance ±1%; Part 0805W8F100JT5E; LCSC C17415
R3: 5.1kΩ; R_0805; Overload Voltage (Max) 150V; Tolerance ±1%; Part 0805W8F5101T5E; LCSC C27834
R8: 470Ω; R_0603; Overload Voltage (Max) 75V; Tolerance ±1%; Part 0603WAF4700T5E; LCSC C23179
R9, R10: 4.7kΩ; R_0603; Overload Voltage (Max) 75V; Tolerance ±1%; Part 0603WAF4701T5E; LCSC C23162
R11: 49.9kΩ; R_0603; Overload Voltage (Max) 75V; Tolerance ±1%; Part 0603WAF4992T5E; LCSC C23184
R16, R17: 1kΩ; R_0603; Overload Voltage (Max) 75V; Tolerance ±1%; Part 0603WAF1001T5E; LCSC C21190
R18, R19, R20, R21, R22, R23: 10kΩ; R_0603; Overload Voltage (Max) 75V; Tolerance ±1%; Part 0603WAF1002T5E; LCSC C25804
S1, S2: Tactile Button, 160gf; SW-SMD_4P-L5.1-W5.1-P3.70-LS6.5-TL-2; Voltage Rating (Dc) 12V; Part TS-1187A-B-A-B; LCSC C318884
TP_3v3: TestPoint; PinHeader_1x01_P1.00mm_Vertical
TP_GND1: TestPoint; PinHeader_1x01_P1.00mm_Vertical
TP_PWM1: TestPoint; PinHeader_1x01_P1.00mm_Vertical
TP_VBUS1: TestPoint; PinHeader_1x01_P1.00mm_Vertical
TP_Vin1: TestPoint; PinHeader_1x01_P1.00mm_Vertical
U1: HUSB238_xxxDD; WDFN-10-1EP_3x3mm_P0.5mm_EP1.8x2.5mm; LCSC C7471904
U2: STM8S003F3P6TR; TSSOP-20_4.4x6.5mm_P0.65mm; Operating Voltage Range 2.95V~5.5V; Low Voltage Detection T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 2.95V~5.5V; Part STM8S003F3P6TR; LCSC C52717
U3: USBLC6-2SC6; SOT-23-6; LCSC C7519
U7: HT7533; SOT-89-3_L4.5-W2.5-P1.50-LS4.2-BR; Output Voltage 3.3V; Dropout Voltage 55mV@(1mA); Part HT7533-1; LCSC C14289

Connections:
+3.3V: C7.1, C17.1, J3.1, J4.1, R9.1, R10.1, R20.1, R21.1, R22.1, TP_3v3.1 (1_1), U2.9 (VDD), U7.3 (VOUT)
/1+: J1.8; also elsewhere on the board
/1-: J1.6; also elsewhere on the board
/2+: J1.4; also elsewhere on the board
/2-: J1.2; also elsewhere on the board
/3+: J1.3; also elsewhere on the board
/3-: J1.1; also elsewhere on the board
/4+: J1.7; also elsewhere on the board
/4-: J1.5; also elsewhere on the board
/LED_driver1/Vin: Q1.3 (D), TP_Vin1.1 (1_1); also elsewhere on the board
/NRST: C18.1, J3.4, R20.2, U2.4 (NRST)
/PC3: D5.2, U2.13 (PC3)
/PC4: D6.2, U2.14 (PC4)
/PC6/PWM: R23.1, TP_PWM1.1 (1_1), U2.16 (PC6); also elsewhere on the board
/PD1/SWIM: J3.2, U2.18 (PD1)
/PD3/S1: R22.2, S1.1 (A), U2.20 (PD3)
/PD4/S2: R21.2, S2.1 (A), U2.1 (PD4)
/PD5/UART_TX: J4.2, U2.2 (PD5)
/PD6/UART_RX: J4.3, U2.3 (PD6)
/SCL: R9.2, U1.7 (SCL), U2.12 (PB4)
/SDA: R10.2, U1.6 (SDA), U2.11 (PB5)
/USB_VBUS: F1.1, J2.A9B4 (VBUS), J2.B9A4 (VBUS)
GND: C1.2, C6.2, C7.2, C16.2, C17.2, C18.2, D9.2, J2.A12B1 (GND), J2.B12A1 (GND), J2.S1 (SHIELD), J3.3, J4.4, R8.2, R16.2, R17.2, R18.2, R23.2, S1.3 (C), S2.3 (C), TP_GND1.1 (1_1), U1.11 (GND), U2.7 (VSS), U3.2 (GND), U7.1 (GND); also elsewhere on the board
unnamed: D5.1, R16.1
unnamed: D6.1, R17.1
unnamed: J2.A5 (CC1), U3.1 (I/O1)
unnamed: J2.B5 (CC2), U3.3 (I/O2)
unnamed: D8.1, Q1.1 (G), R3.1, R11.2
unnamed: R8.1, R19.2
unnamed: U1.4 (CC1), U3.6 (I/O1)
unnamed: U1.5 (CC2), U3.4 (I/O2)
unnamed: J2.A6 (D+), J2.B6 (D+), U1.2 (D+)
unnamed: J2.A7 (D-), J2.B7 (D-), U1.3 (D-)
unnamed: R3.2, U1.10 (GATE)
unnamed: R19.1, U1.9 (ISET)
unnamed: C1.1, R1.2, U1.1 (VIN)
unnamed: R18.1, U1.8 (VSET)
unnamed: C16.1, U2.8 (VCAP)
VBUS: C6.1, D8.3, D9.1, F1.2, Q1.2 (S), R1.1, R11.1, TP_VBUS1.1 (1_1), U7.2 (VIN)

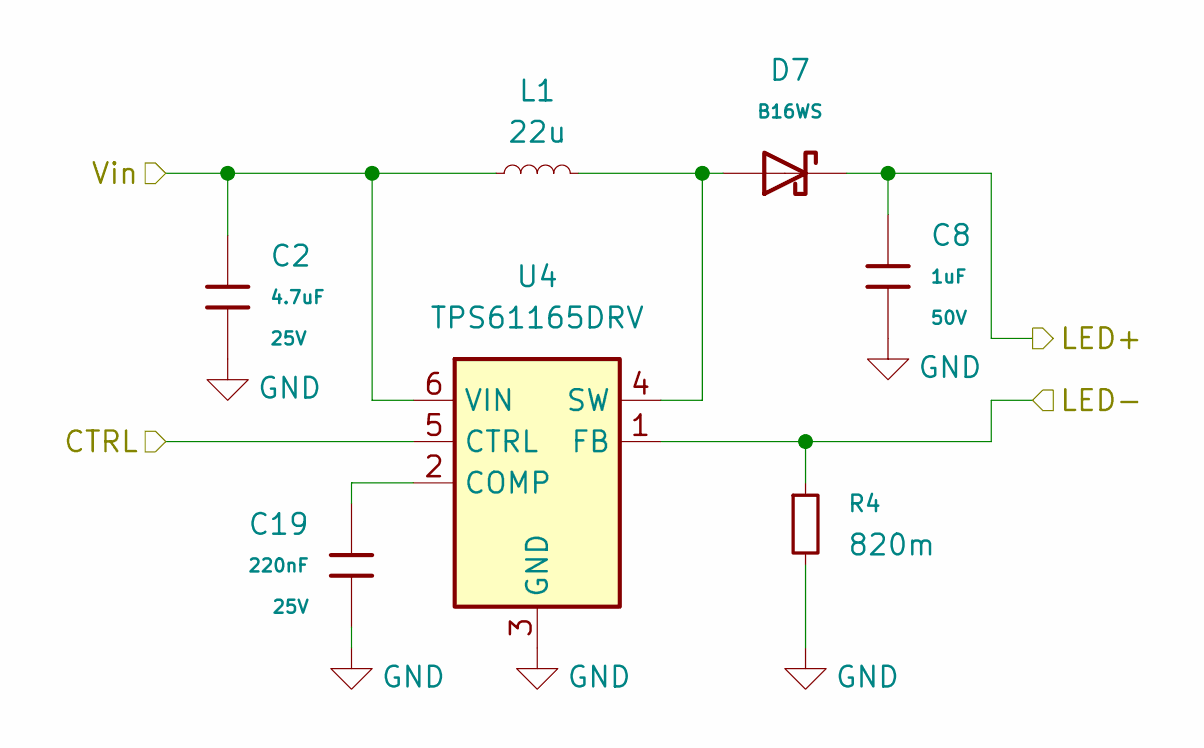
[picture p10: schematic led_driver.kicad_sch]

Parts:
C2: 4.7uF; C_0805; Voltage Rated 25V; Tolerance ±10%; Part CL21A475KAQNNNE; LCSC C1779
C8: 1uF; C_0603; Voltage Rated 50V; Tolerance ±10%; Part CL10A105KB8NNNC; LCSC C15849
C19: 220nF; C_0603; Voltage Rated 25V; Tolerance ±10%; Part CL10B224KA8NNNC; LCSC C21120
D7: B16WS; D_SOD-323; Forward Voltage (Vf@If) 0.7V@1.0A; Reverse Voltage (Vr) 60V; Part B16WS; LCSC C7420327
L1: 22u; L_Cenker_CKCS4030; LCSC C354592
R4: 820m; R_1206_3216Metric; LCSC C2907361
U4: TPS61165DRV; WSON-6-1EP_2x2mm_P0.65mm_EP1x1.6mm; LCSC C122568

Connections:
/3+: C8.1, D7.1; also elsewhere on the board
/3-: R4.1, U4.1 (FB); also elsewhere on the board
/LED_driver1/Vin: C2.1, L1.1, U4.6 (VIN); also elsewhere on the board
/PC6/PWM: U4.5 (CTRL); also elsewhere on the board
GND: C2.2, C8.2, C19.2, R4.2, U4.3 (GND), U4.7 (GND); also elsewhere on the board
unnamed: C19.1, U4.2 (COMP)
unnamed: D7.2, L1.2, U4.4 (SW)

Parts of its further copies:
C3, C4, C5: 4.7uF; C_0805; Voltage Rated 25V; Tolerance ±10%; Part CL21A475KAQNNNE; LCSC C1779
C9, C10, C11: 1uF; C_0603; Voltage Rated 50V; Tolerance ±10%; Part CL10A105KB8NNNC; LCSC C15849
C20, C21, C22: 220nF; C_0603; Voltage Rated 25V; Tolerance ±10%; Part CL10B224KA8NNNC; LCSC C21120
D10, D11, D12: B16WS; D_SOD-323; Forward Voltage (Vf@If) 0.7V@1.0A; Reverse Voltage (Vr) 60V; Part B16WS; LCSC C7420327
L2, L3, L4: 22u; L_Cenker_CKCS4030; LCSC C354592
R5, R6, R7: 820m; R_1206_3216Metric; LCSC C2907361
U5, U11, U12: TPS61165DRV; WSON-6-1EP_2x2mm_P0.65mm_EP1x1.6mm; LCSC C122568

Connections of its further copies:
/1+: C10.1, D11.1; also elsewhere on the board
/1-: R6.1, U11.1 (FB); also elsewhere on the board
/2+: C11.1, D12.1; also elsewhere on the board
/2-: R7.1, U12.1 (FB); also elsewhere on the board
/4+: C9.1, D10.1; also elsewhere on the board
/4-: R5.1, U5.1 (FB); also elsewhere on the board
/LED_driver1/Vin: C3.1, C4.1, C5.1, L2.1, L3.1, L4.1, U5.6 (VIN), U11.6 (VIN), U12.6 (VIN); also elsewhere on the board
/PC6/PWM: U5.5 (CTRL), U11.5 (CTRL), U12.5 (CTRL); also elsewhere on the board
GND: C3.2, C4.2, C5.2, C9.2, C10.2, C11.2, C20.2, C21.2, C22.2, R5.2, R6.2, R7.2, U5.3 (GND), U5.7 (GND), U11.3 (GND), U11.7 (GND), U12.3 (GND), U12.7 (GND); also elsewhere on the board
unnamed: C20.1, U5.2 (COMP)
unnamed: D10.2, L2.2, U5.4 (SW)
unnamed: C21.1, U11.2 (COMP)
unnamed: D11.2, L3.2, U11.4 (SW)
unnamed: C22.1, U12.2 (COMP)
unnamed: D12.2, L4.2, U12.4 (SW)

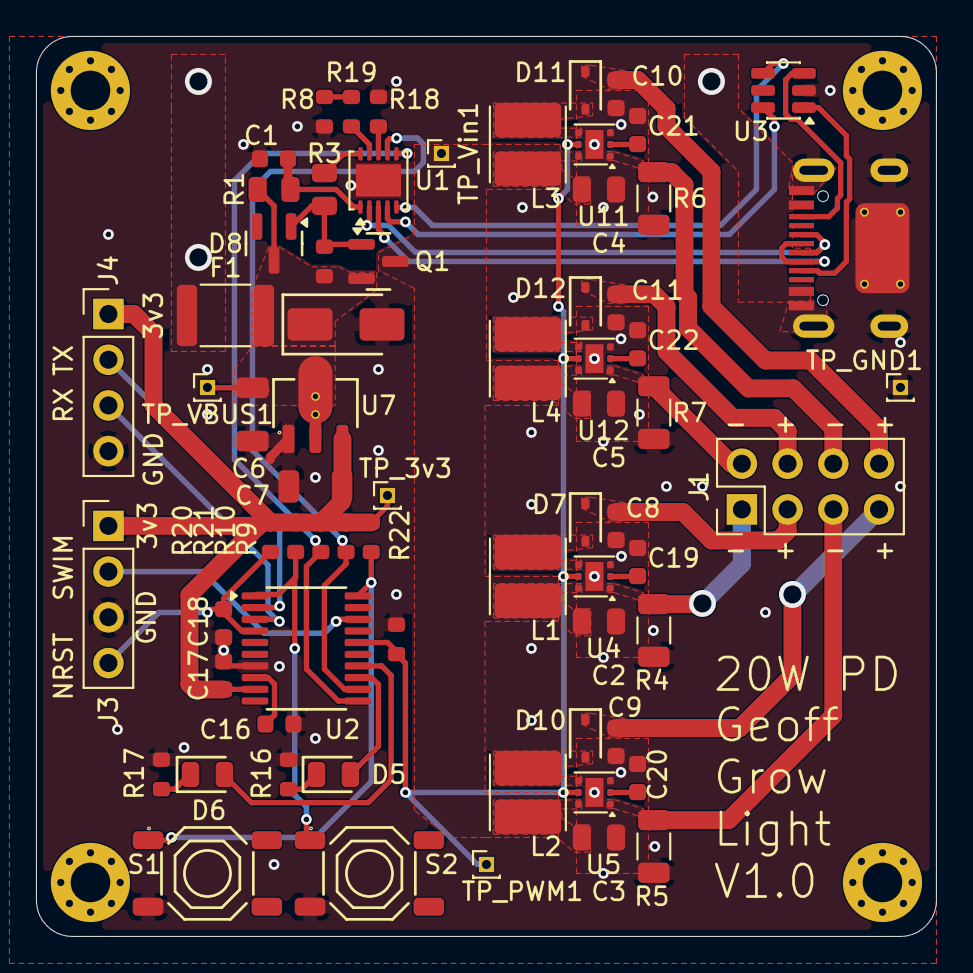
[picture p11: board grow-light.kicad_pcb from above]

Board: 4 copper layers, 50.0 x 50.0 mm, 73 parts (0 on the bottom side), 47 nets.

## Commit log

2026-09-06 Initial commit: grow-light controller and LED panel
    [bom.csv, designators.csv, grow-light-LEDS.kicad_pcb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]
2026-09-06 Update board designs and production outputs
    [bom.csv, designators.csv, grow-light.kicad_pcb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]
2026-09-09 Release v1.0
    [bom.csv, designators.csv, grow-light-LEDS.kicad_pcb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]
